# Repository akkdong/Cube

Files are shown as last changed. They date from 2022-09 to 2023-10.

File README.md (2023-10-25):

# M1
ESP32_WT32-SC01, Barometer, GPS, Audio, Battery bank

# M2
ESP32-S3-HMI-V3, Barometer, GPS, Audio, SD, Battery charge

# M3
M5Paper, EPS32-C3, Baromter, GPS, Audio

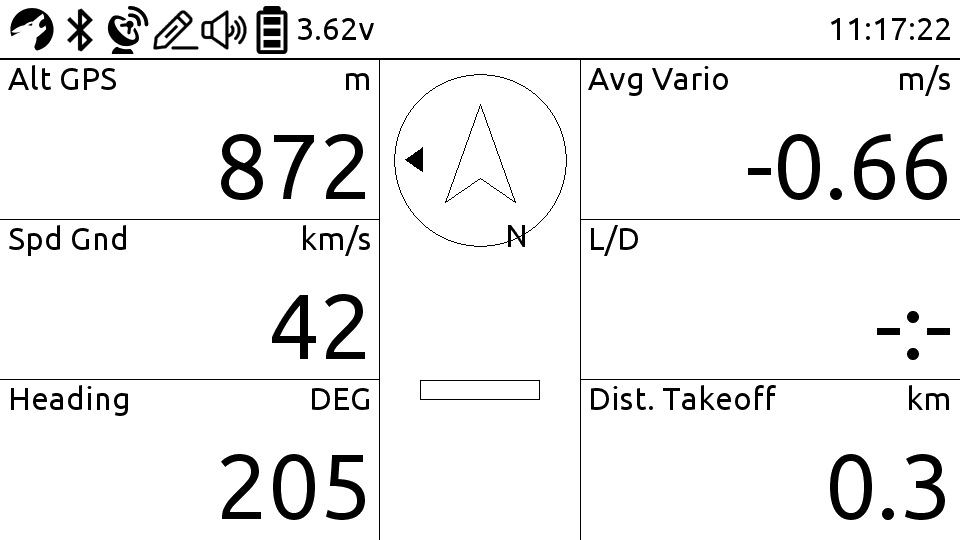
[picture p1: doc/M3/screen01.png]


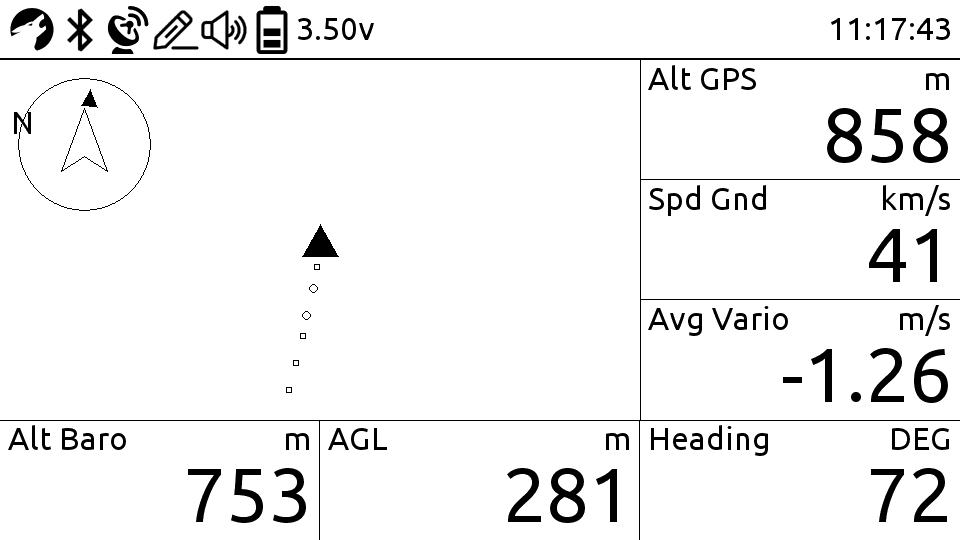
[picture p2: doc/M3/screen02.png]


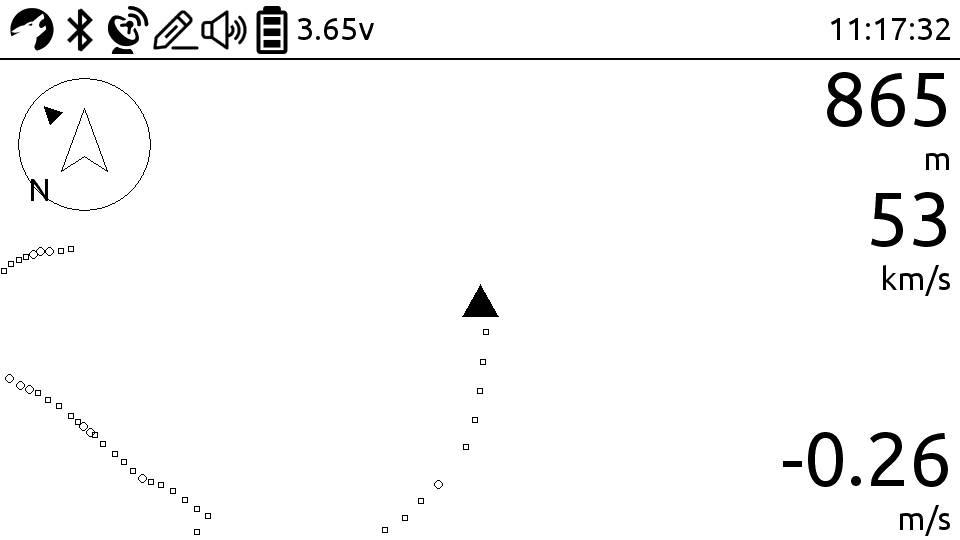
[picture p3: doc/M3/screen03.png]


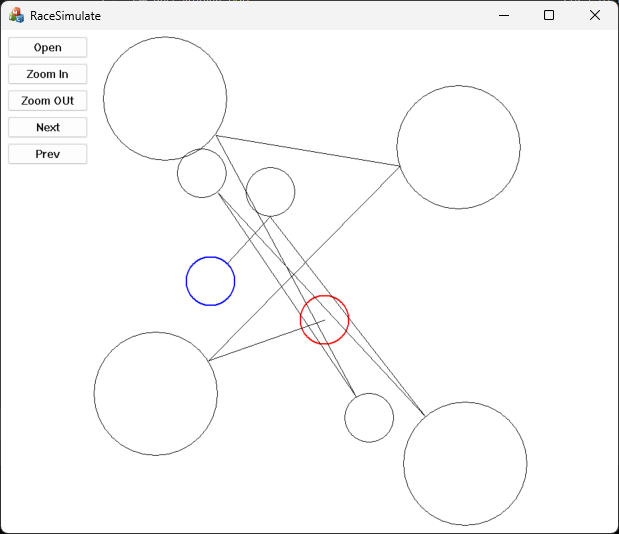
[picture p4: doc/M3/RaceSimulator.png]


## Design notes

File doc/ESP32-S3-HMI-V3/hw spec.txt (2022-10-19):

설명:

ESP32-S3 듀얼 코어 Xtensa 32 비트 LX7 마이크로 프로세서, 384KB ROM, 512KB sram으로 최대 240 MHz. 2.4GHz 와이파이 및 블루투스 5
PSRAM: 2MB 플래시: 8MB
저장: 마이크로 SD 카드 슬롯
디스플레이: 480 × 800 해상도, I2C 정전 식 터치 패널, 4.3 인치 디스플레이
디스플레이 인터페이스: 16 비트, 8080 병렬 통신
오디오: 코덱, 오디오 앰프, 내장 마이크, 스피커
USB: 1x USB-C OTG (DFU/CDC) 포트, 1x USB-C 디버그 포트
센서: 3 축 가속도계, 3 축 자이로 스코프, 온도 및 습도 센서
주변 인터페이스: I2C, SPI, GPIOs
기타: 웨이크 업 및 리셋 버튼, 전원 스위치
전원 공급 장치: 5V / 1A
치수: 110x61x13.5mm

Peripherals

RM68120  		TFT LCD 480x800 4.3inch
FT5X06(0x38)	True Multi-Touch Capacitive TouchPanel Controller
TCA9554(0x3C)	I/O Expander
HTU32D(0x40)	Digital Relative Humidity sensor with Temperature output
ES8311(0x18)	Low Power Mono Audio CODEC
MPU6050(0x68)	6-Axis (Gyro + Accelerometer) MEMS
BMP280(0x76)

TPS63001		High-Efficient Single Inductor Buck-Boost Converter With 1.8-A Switches
NS4150		3W Mono Class D Audio Amplifier

HDC1080(0x40)	High Accuracy Digital Humidity Sensor with Temperature Sensor

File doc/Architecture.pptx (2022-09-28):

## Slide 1

Variometer

MCU (ESP32)

Bluetooth: HID(Keyboard), UART(Variometer)

Mobile

Battery
18650x4

Charger
Booster

S/W

Button(s)
Rotary

Sensor
Pressure
IMU

GPS

Audio
AMP
SPEAKER

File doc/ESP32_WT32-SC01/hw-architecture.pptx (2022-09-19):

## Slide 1

Main Board w/ LCD

Sub Board : GPS, Pressure Sensor, Amplifier, Power-switch, Buttons

Charger Board: Charger & Booster

UART

PWM

I2C

Charger

Pressure Sensor

Amplifier

GPS

Booster

BTN_xxxx

Enter/
Power

Left

Up

Right

PWR_ON

3v3

5v

Down

Prog/
Debug

On/Off

Power Input

Power Switch

Power On Sequence
1. Turn on Charger board
2. Press Enter/Power in Sub Board → Turn on Charge board while holding down Enter/Power
3. Hold down Enter/Power until MCU boot-up
4. Set to high PWR_ON
Power Of Sequence
1. MCU prepare power-off
2. Set to low PWR_ON

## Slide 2

7

1.6

1.6

20

4.2

7.8

7

Top | 2 | 49 | 2 | 27 | 25.4
LCD + Main board | 7 | 47 | 9 | 25 | 23.4
Connector | 7.8 | 40 | 16.8 | 18 | 16.4
Base board (PCB) | 1.6 | 32.2 | 18.4 | 10.2 | 8.6
Supporter | 7 | 30.6 | 25.4 | 8.6 | 7
Battery Charger (PCB) | 1.6 | 23.6 | 27 | 1.6 | -1.6
Battery Holder | 20 | 22 | 47 | -20 | -21.6
Bottom | 2 | 2 | 49 | -22 | -23.6

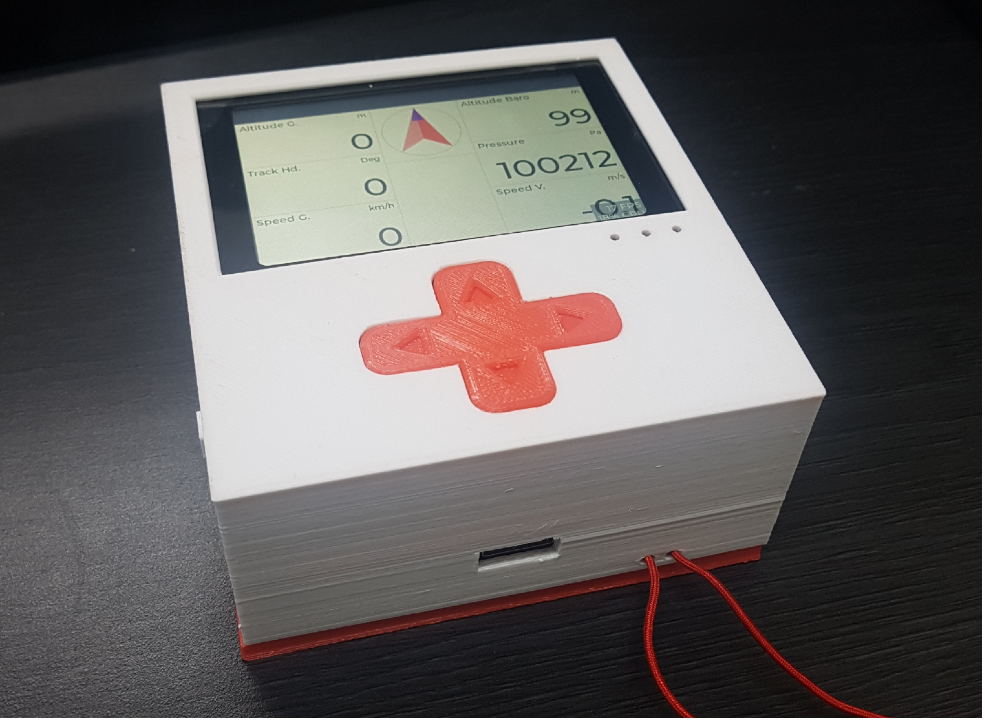
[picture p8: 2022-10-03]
doc/m1-working.png

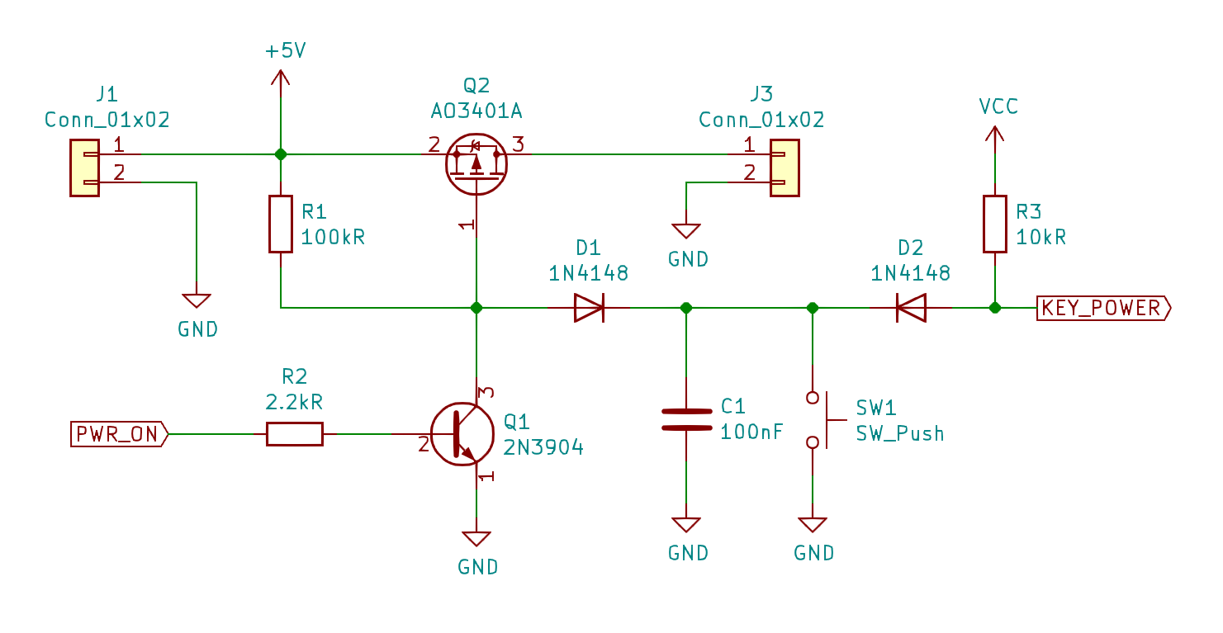
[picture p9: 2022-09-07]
doc/ESP32_WT32-SC01/power-switch.png

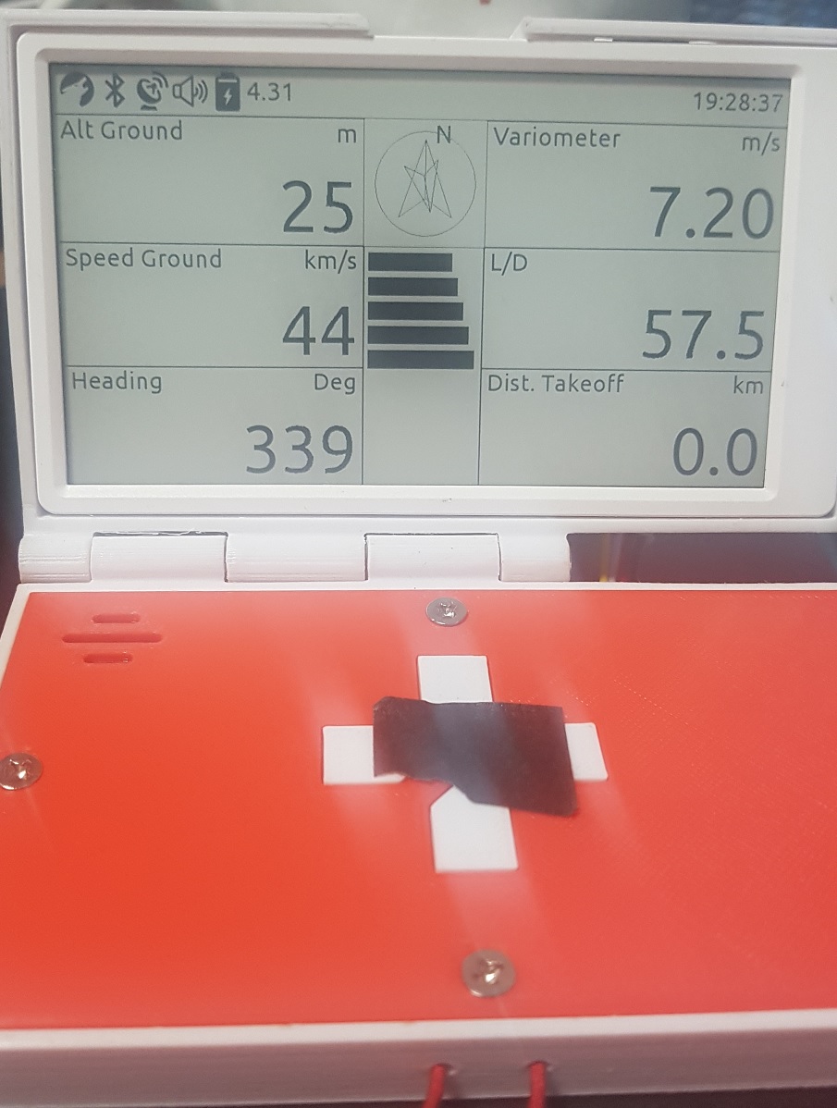
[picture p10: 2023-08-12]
doc/m3-working.jpg

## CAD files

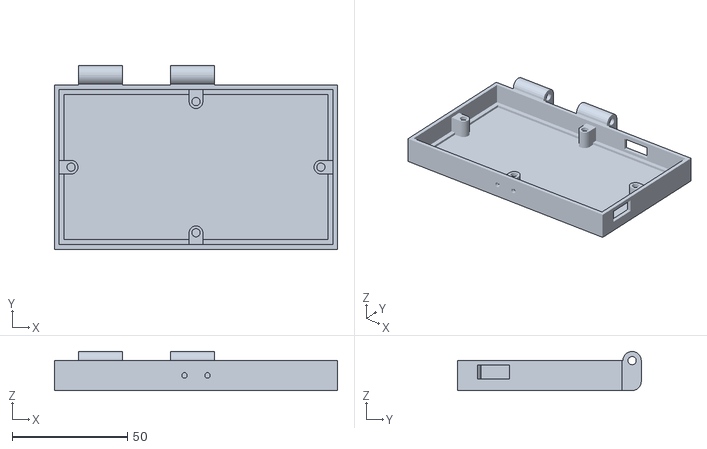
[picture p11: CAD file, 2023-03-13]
case/M3/Main Holder (Meshed).stl
123.0 x 79.8 x 17.0

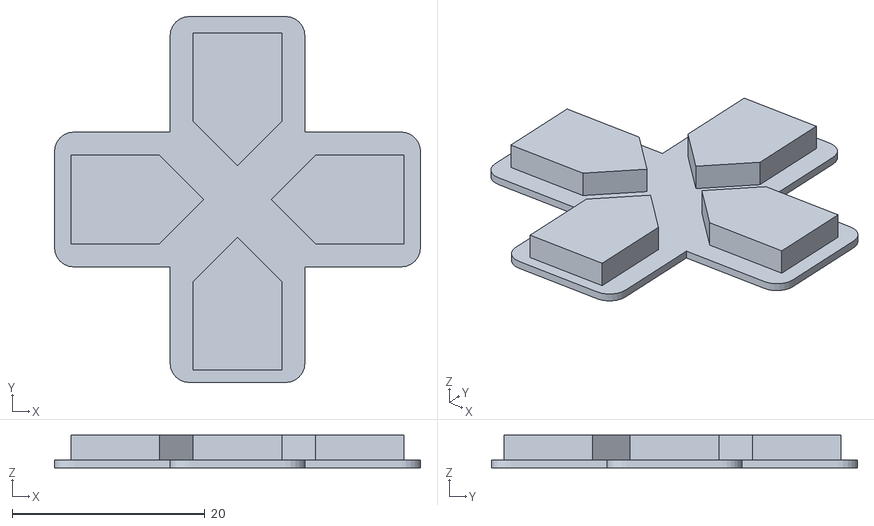
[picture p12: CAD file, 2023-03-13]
case/M3/Main Button (Meshed).stl
38.0 x 38.0 x 3.40

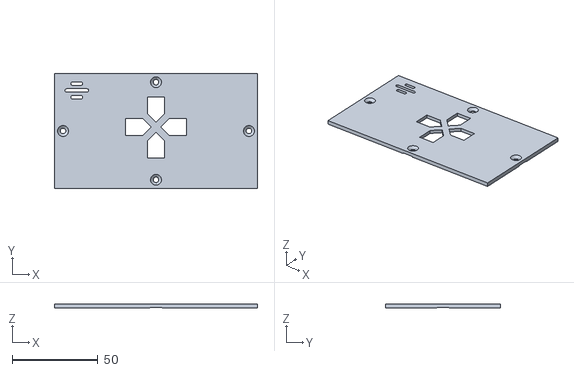
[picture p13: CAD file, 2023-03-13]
case/M3/Main Cover (Meshed).stl
118.6 x 67.0 x 2.40

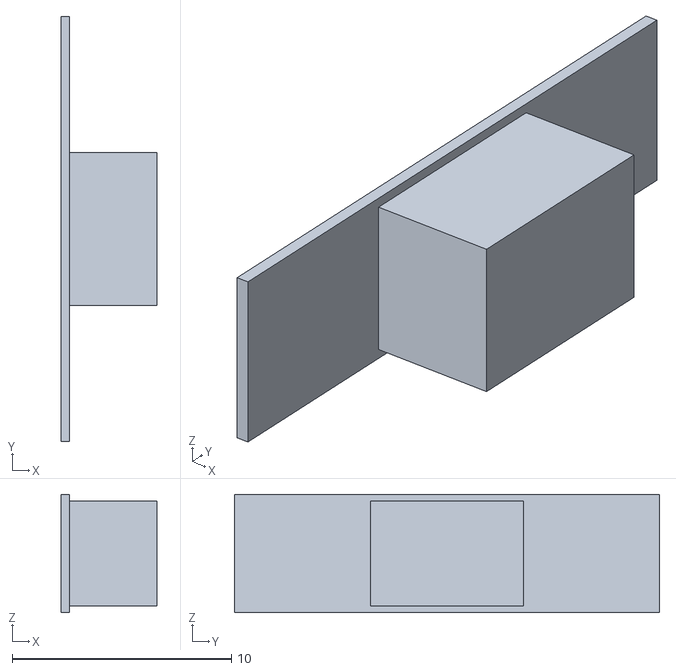
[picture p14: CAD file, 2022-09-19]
case/M1/Button-Power (Meshed).stl
4.40 x 19.4 x 5.40

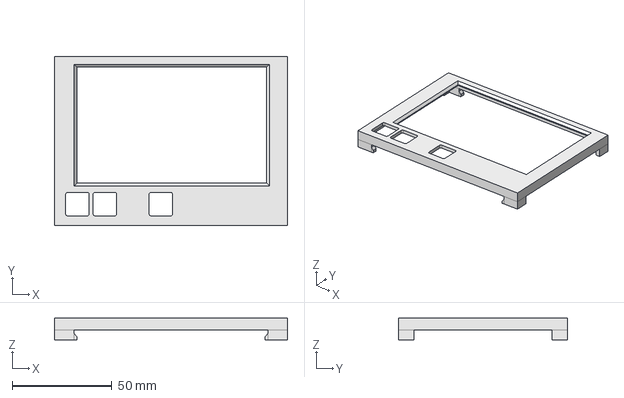
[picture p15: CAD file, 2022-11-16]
case/M2/Case-M2.FCStd
117.0 x 85.0 x 10.8 mm

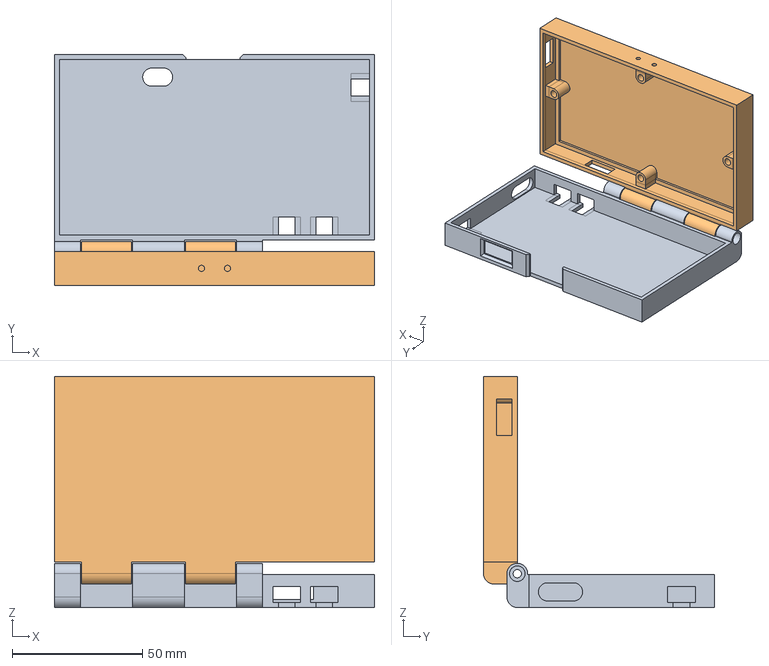
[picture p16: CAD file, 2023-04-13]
case/M3/M3.FCStd
123.0 x 88.8 x 88.8 mm
Disp Holder
Main Holder

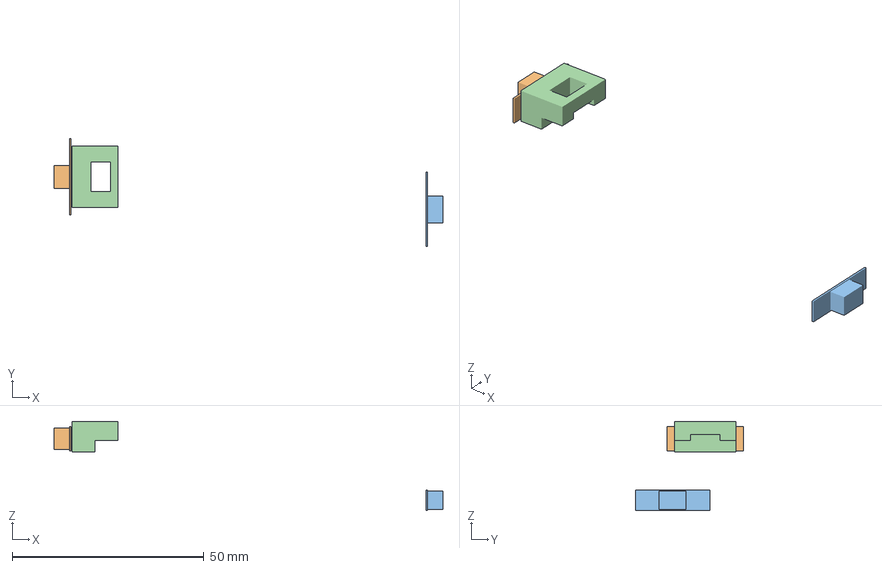
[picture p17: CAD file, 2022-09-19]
case/M1/Cube-Vario.FCStd
101.4 x 28.2 x 23.3 mm
Button-Guide
Button-Enter
Button-Power
Button-Guide (Meshed)
Button-Enter (Meshed)
Button-Power (Meshed)

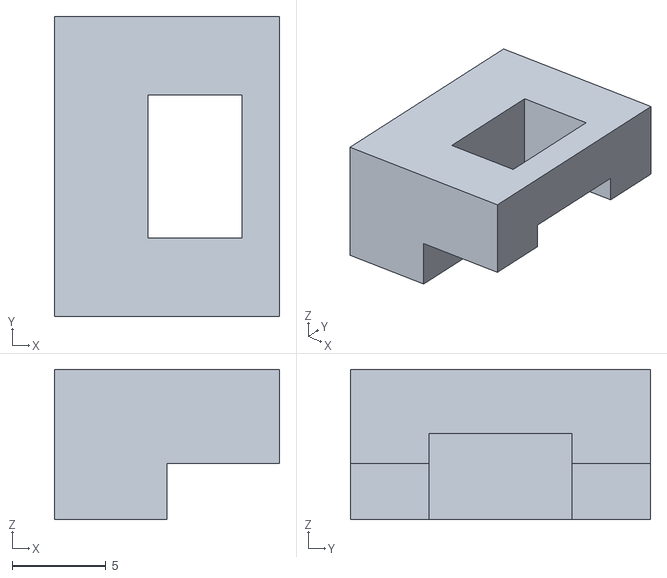
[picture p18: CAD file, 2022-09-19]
case/M1/Button-Guide (Meshed).stl
12.0 x 16.0 x 8.00

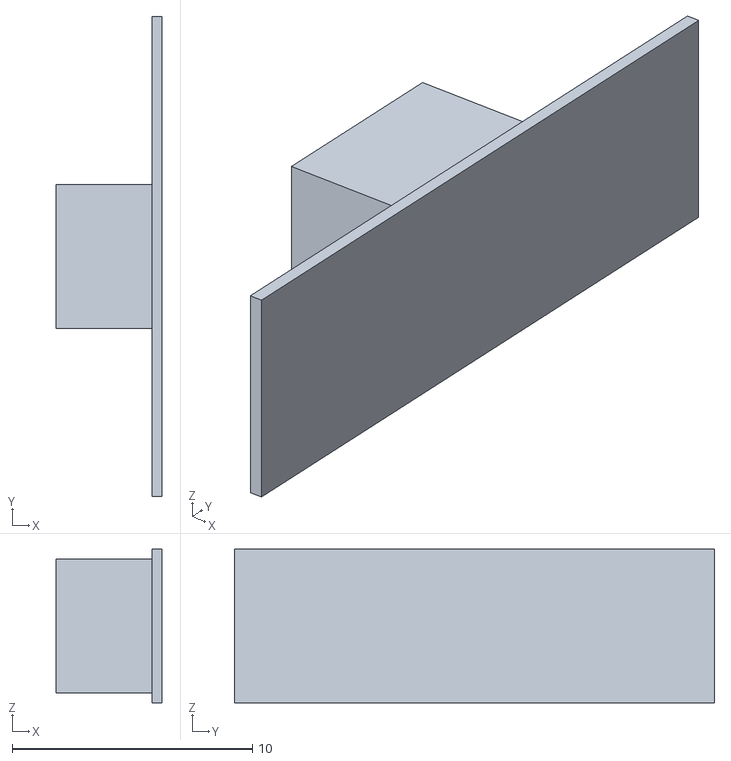
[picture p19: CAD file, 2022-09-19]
case/M1/Button-Enter (Meshed).stl
4.40 x 20.0 x 6.40

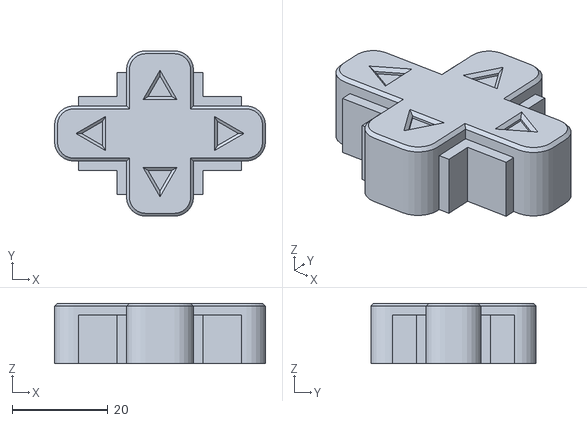
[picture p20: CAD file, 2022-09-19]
case/M1/Button-Cross (Meshed).stl
44.0 x 34.5 x 12.6

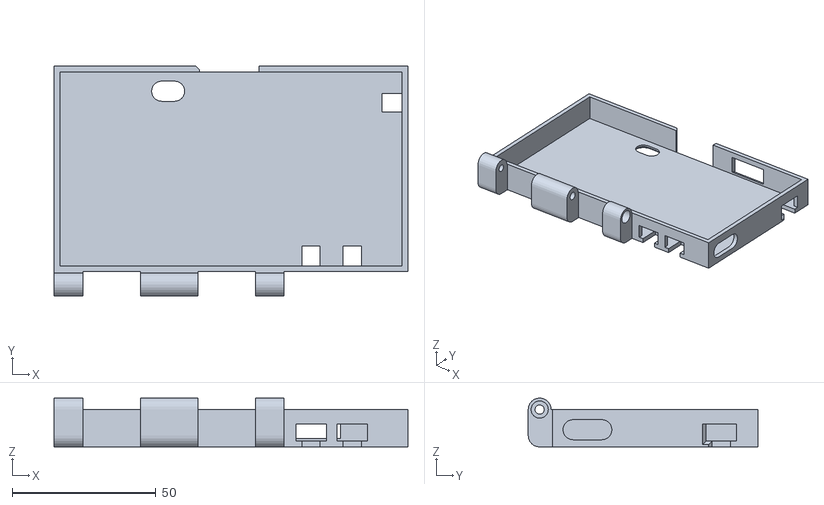
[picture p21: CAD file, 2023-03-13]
case/M3/Disp Holder (Meshed).stl
123.0 x 79.8 x 17.0

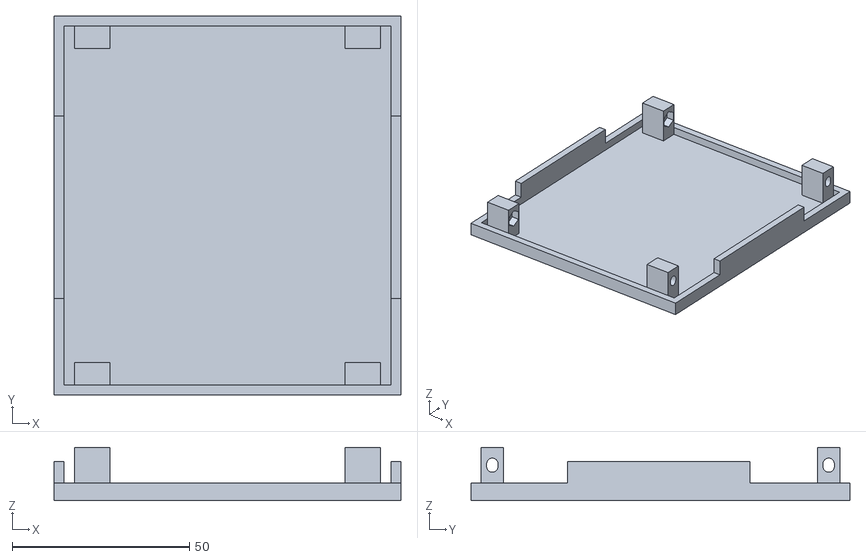
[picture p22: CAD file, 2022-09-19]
case/M1/Base (Meshed).stl
98.0 x 107.0 x 15.0

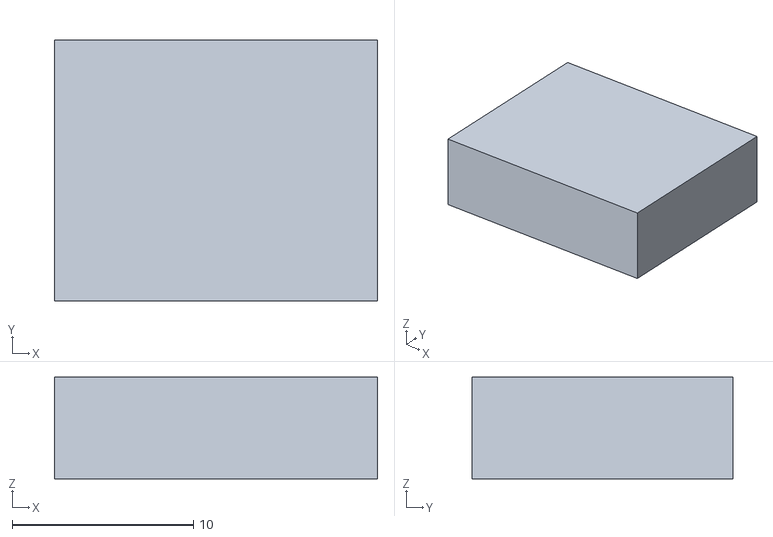
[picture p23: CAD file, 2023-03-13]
case/M3/PSensor Cover (Meshed).stl
17.8 x 14.4 x 5.60

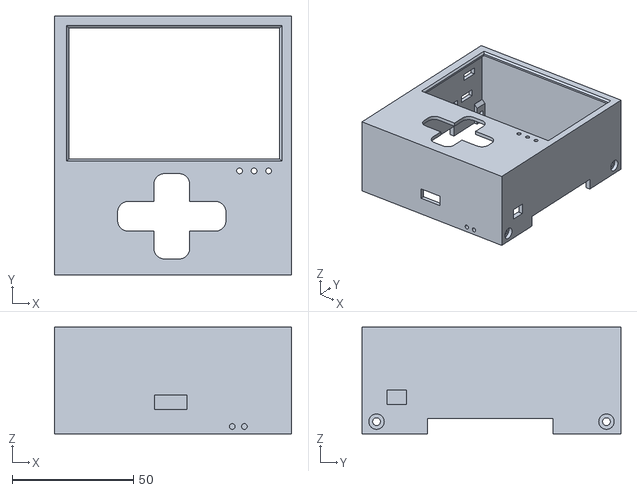
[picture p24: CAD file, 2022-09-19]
case/M1/Cover (Meshed).stl
98.0 x 107.0 x 44.0

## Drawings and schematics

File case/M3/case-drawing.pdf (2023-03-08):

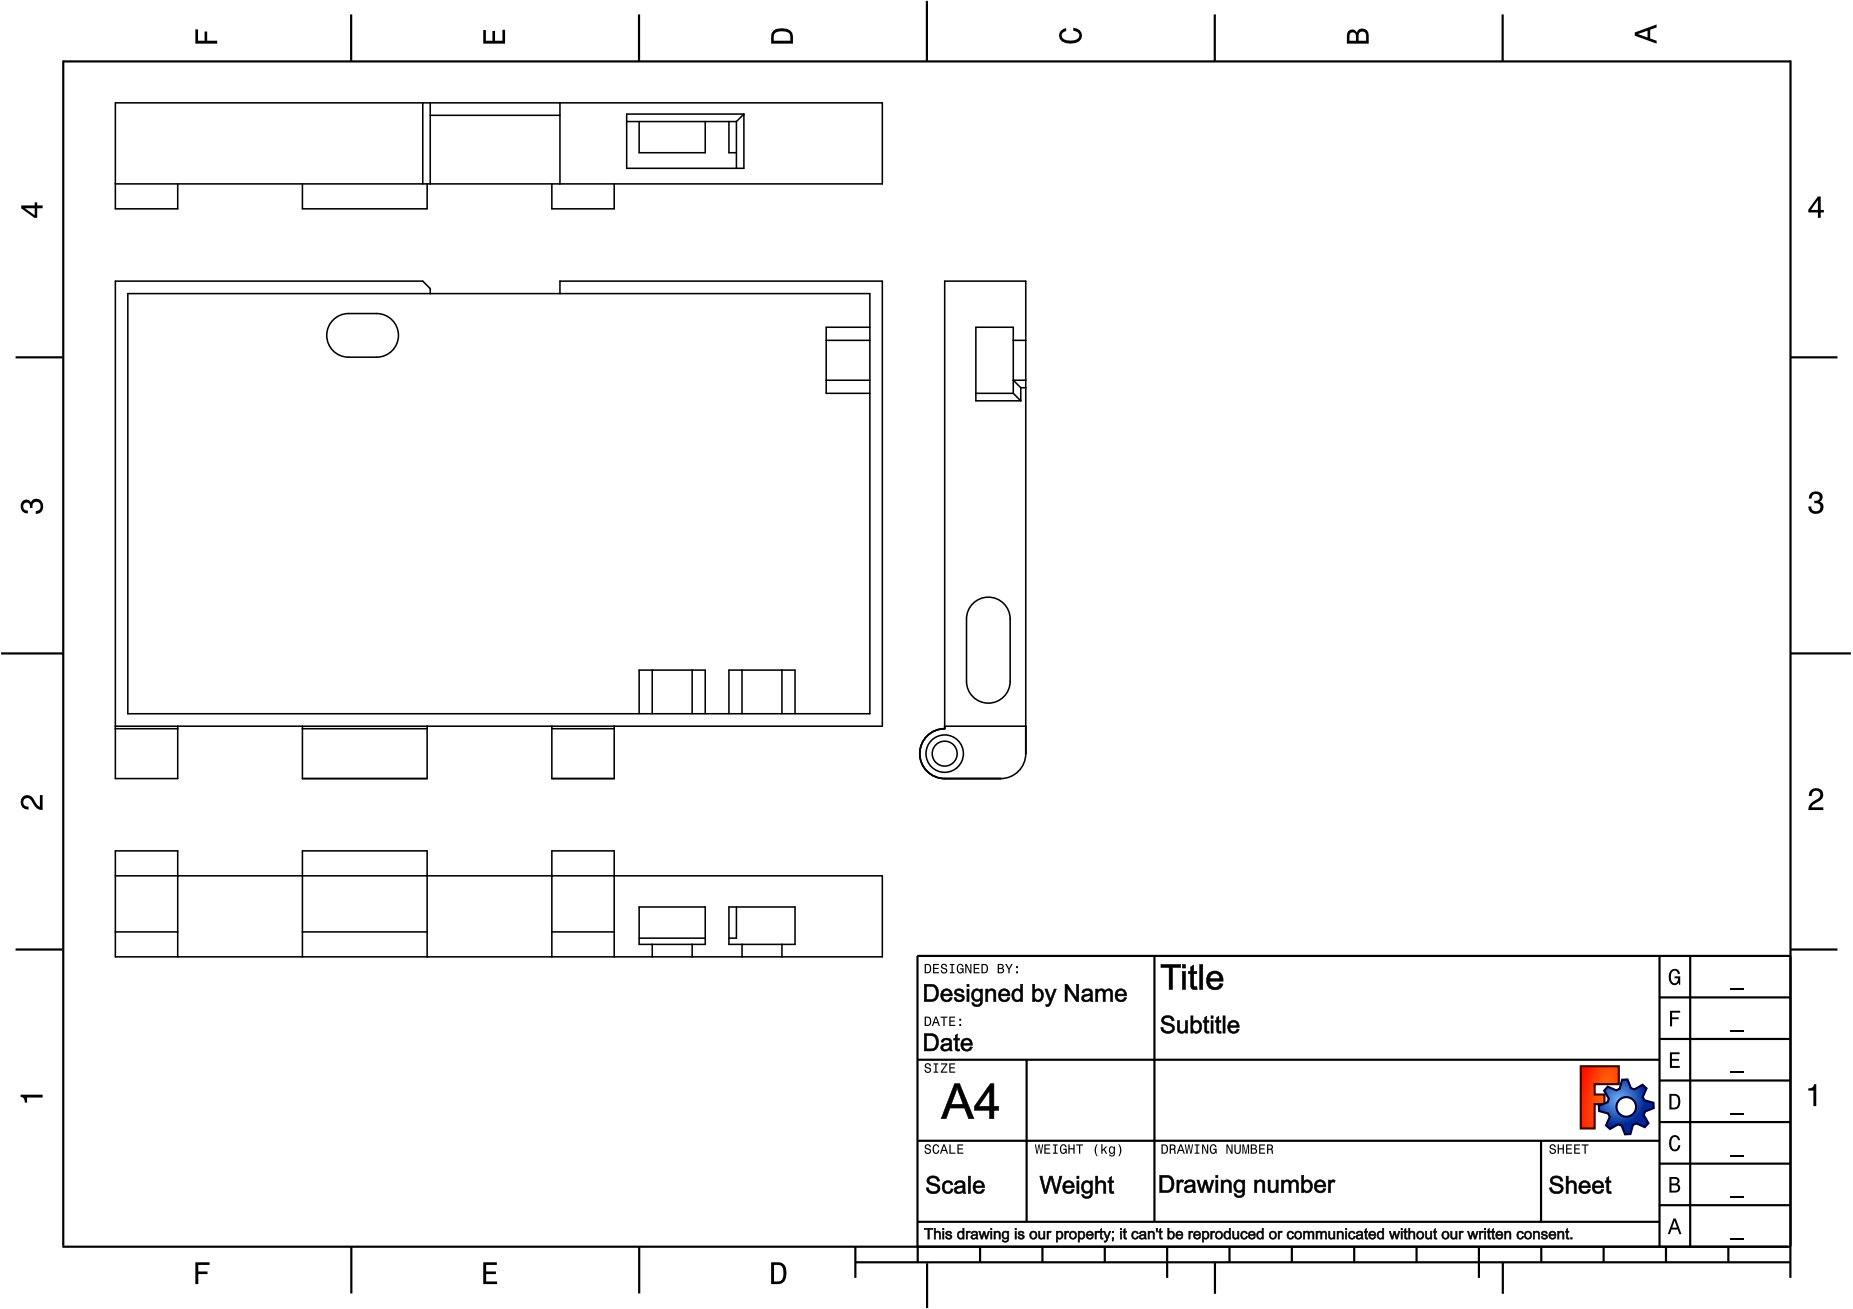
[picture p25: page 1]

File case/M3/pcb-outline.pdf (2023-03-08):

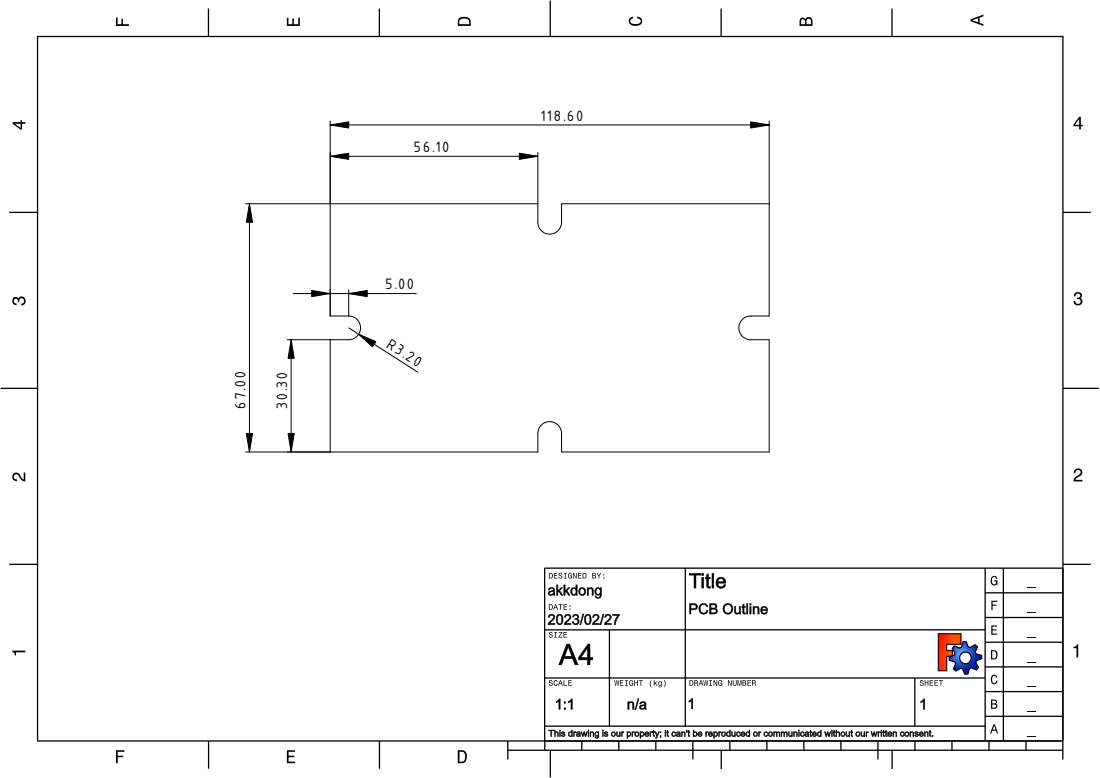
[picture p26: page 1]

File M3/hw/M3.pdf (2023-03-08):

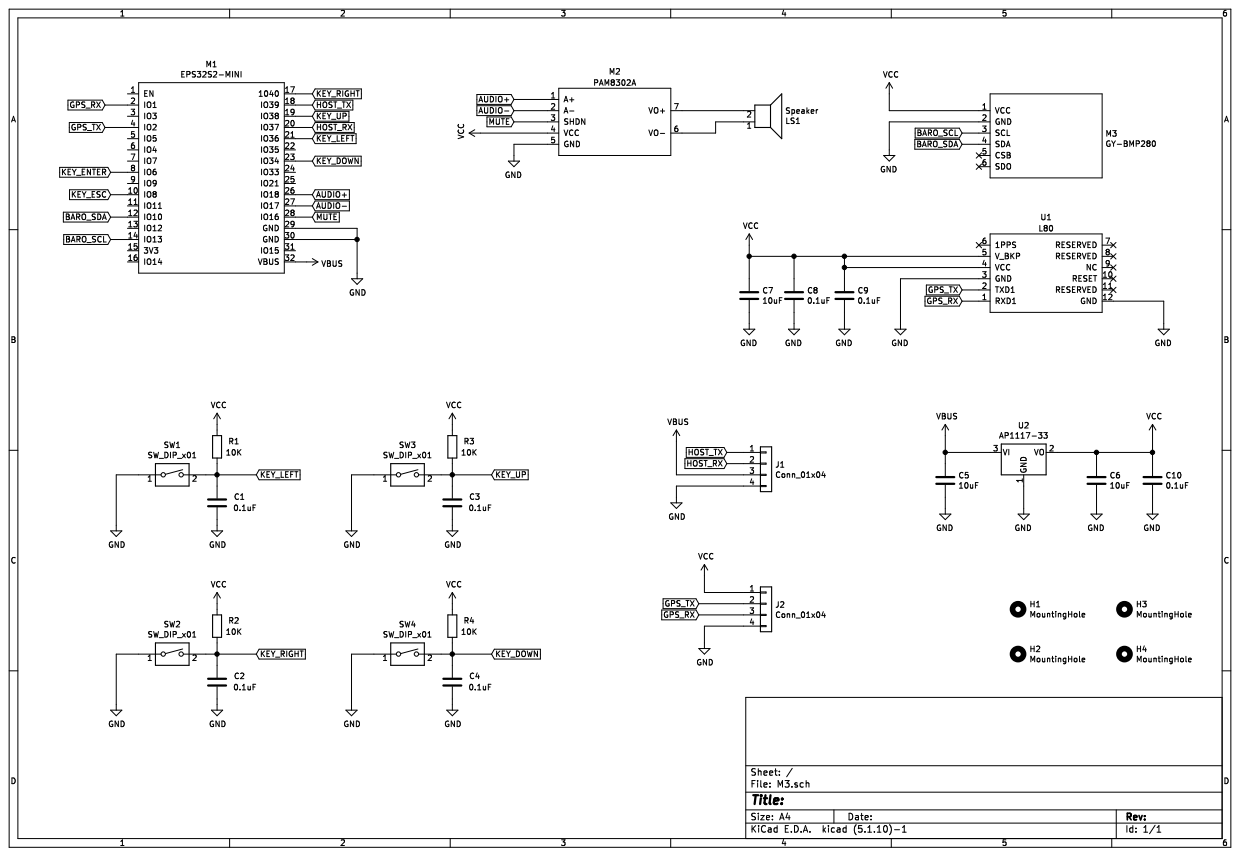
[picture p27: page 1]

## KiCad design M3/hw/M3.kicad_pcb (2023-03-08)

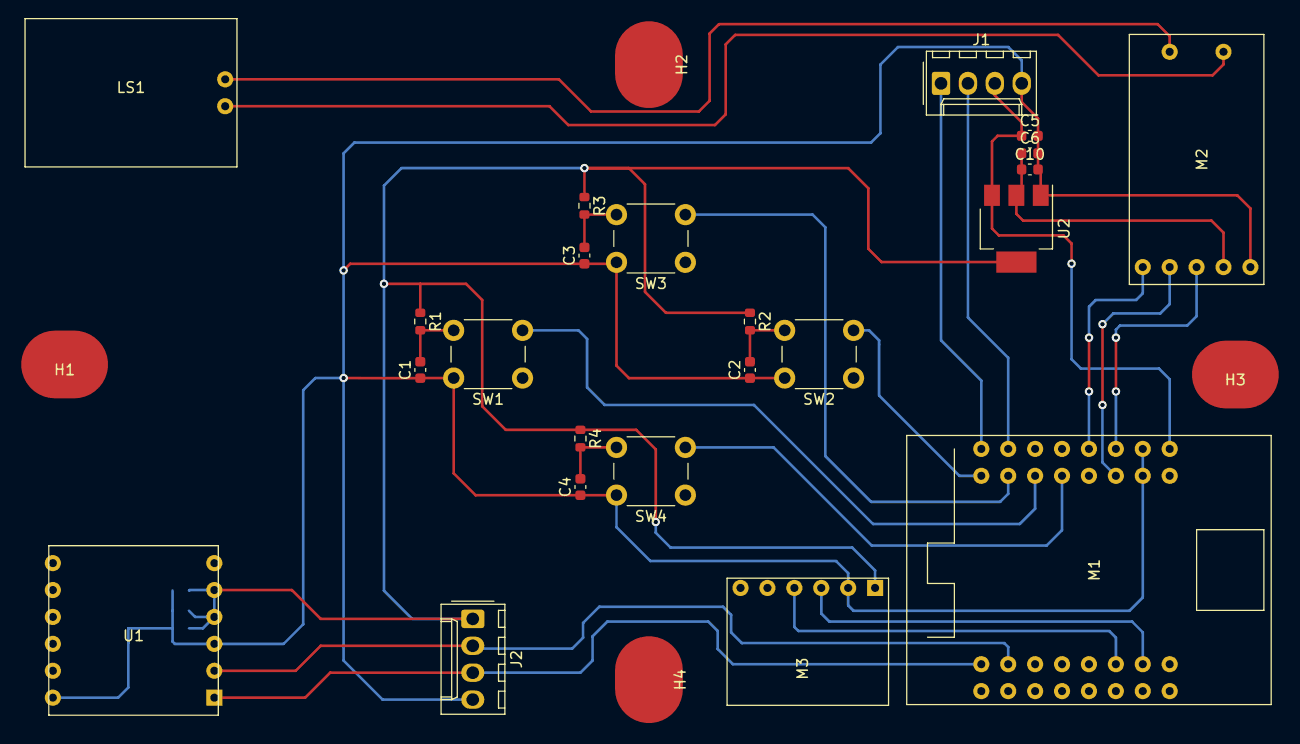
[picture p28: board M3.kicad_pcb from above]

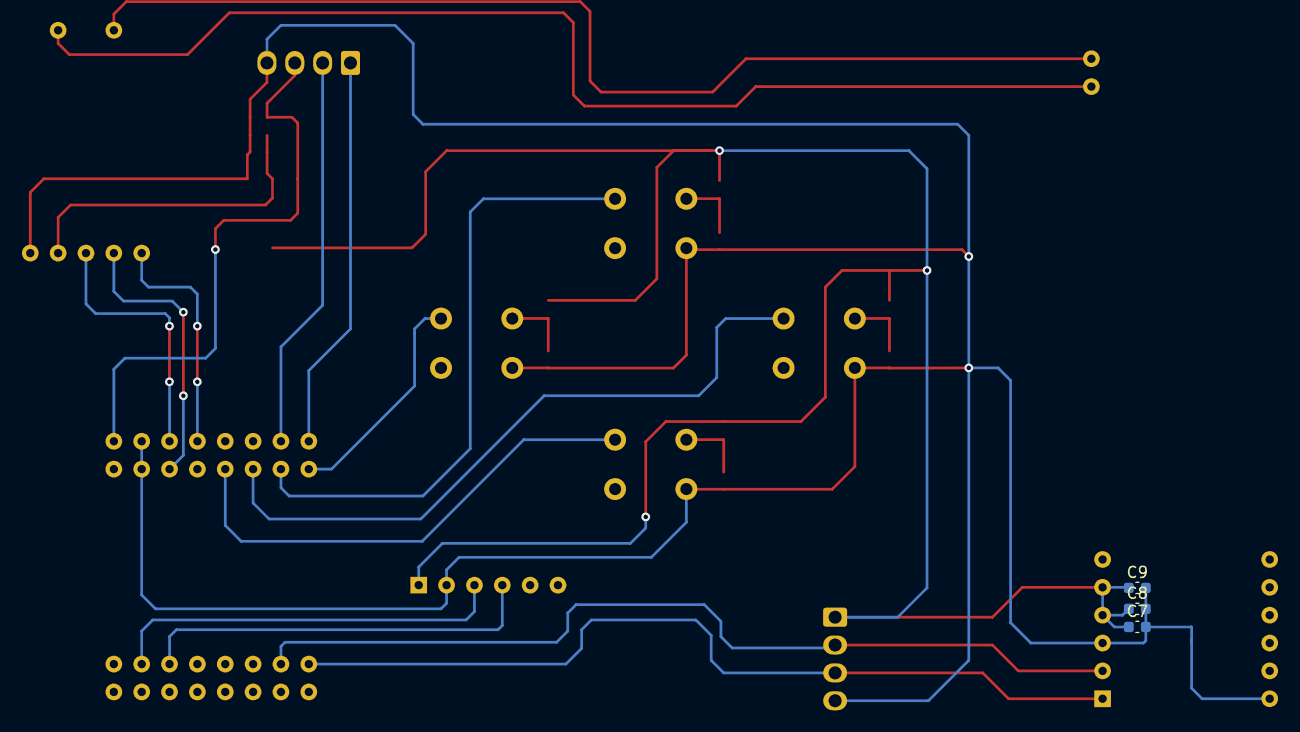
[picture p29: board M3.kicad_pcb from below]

Board: 2 copper layers, 30 parts (3 on the bottom side), 18 nets.

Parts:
C1, C2, C3, C4, C8, C9, C10: 0.1uF; C_0603_1608Metric
C5, C6, C7: 10uF; C_0603_1608Metric
H1, H2, H3, H4: MountingHole; M3_HOLE
J1, J2: Conn_01x04; Molex_KK-254_AE-6410-04A_1x04_P2.54mm_Vertical
LS1: Speaker; ROUND-SPEKAER
M1: EPS32S2-MINI; ESP32S2-MINI
M2: PAM8302A
M3: GY-BMP280
R1, R2, R3, R4: 10K; R_0603_1608Metric
SW1, SW2, SW3, SW4: SW_DIP_x01; SW_PUSH_6mm
U1: L80
U2: AP1117-33; SOT-223-3_TabPin2

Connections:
AUDIO+: M1.26, M2.1
AUDIO-: M1.27, M2.2
BARO_SCL: M1.14, M3.3
BARO_SDA: M1.12, M3.4
GND: C1.1, C2.1, C3.1, C4.1, C5.2, C6.2, C7.2, C8.2, C9.2, C10.2, J1.4, J2.4, M1.29, M1.30, M2.5, M3.2, SW1.1, SW2.1, SW3.1, SW4.1, U1.3, U1.12, U2.1
GPS_RX: J2.3, M1.2, U1.1
GPS_TX: J2.2, M1.4, U1.2
HOST_RX: J1.2, M1.20
HOST_TX: J1.1, M1.18
KEY_DOWN: C4.2, M1.23, R4.2, SW4.2
KEY_LEFT: C1.2, M1.21, R1.2, SW1.2
KEY_RIGHT: C2.2, M1.17, R2.2, SW2.2
KEY_UP: C3.2, M1.19, R3.2, SW3.2
MUTE: M1.28, M2.3
unnamed: LS1.1, M2.6
unnamed: LS1.2, M2.7
VBUS: C5.1, J1.3, M1.32, U2.3
VCC: C6.1, C7.1, C8.1, C9.1, C10.1, J2.1, M2.4, M3.1, R1.1, R2.1, R3.1, R4.1, U1.4, U1.5, U2.2

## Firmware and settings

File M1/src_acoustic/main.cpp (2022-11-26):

// main.cpp
//

#include <Arduino.h>
#include "device_defines.h"
#include "logger.h"
#include "app.h"
#include "utils.h"
#include "BLEVario.h"
#include "Variometer.h"
#include "VarioSentence.h"
#include "LocationParser.h"
#include "Beeper.h"
#include "Bme280.h"
#include "FT6206.h"
#include "SineGenerator.h"
#include "Keypad.h"

#define VFILTER_HARINAIR_KF2     1
#define VFILTER_HARINAIR_KF4d    2
#define VFILTER_ROBIN_KF         3

#define USE_KALMAN_FILTER        VFILTER_HARINAIR_KF2

#if USE_KALMAN_FILTER == VFILTER_HARINAIR_KF2
#include "VarioFilter_HarInAirKF2.h"
#elif USE_KALMAN_FILTER == VFILTER_HARINAIR_KF4d
#include "VarioFilter_HarInAirKF4d.h"
#elif USE_KALMAN_FILTER == VFILTER_ROBIN_KF
#include "VarioFilter_RobinKF.h"
#else
#error "Invalid vario kalman-filter"
#endif


//
// button
//


//
// baro-settings
//

static Bme280Settings varioSettings() 
{
	return {
		.mode = Bme280Mode::Normal,
		.temperatureOversampling = Bme280Oversampling::X2,
		.pressureOversampling = Bme280Oversampling::X16,
		.humidityOversampling = Bme280Oversampling::Off,
		.filter = Bme280Filter::Off,
		.standbyTime = Bme280StandbyTime::Ms0_5			
	};
}

//
Bme280TwoWire	baro;
SineGenerator	beep;
FT6206			touch;

Variometer      vario;
LocationParser  locParser;
VarioSentence   varioNmea(VARIOMETER_DEFAULT_NMEA_SENTENCE);
Beeper          beeper;

#if USE_KALMAN_FILTER == VFILTER_HARINAIR_KF2
VarioFilter_HarInAirKF2     varioFilter;
#elif USE_KALMAN_FILTER == VFILTER_HARINAIR_KF4d
VarioFilter_HarInAirKF4d    varioFilter;
#elif USE_KALMAN_FILTER == VFILTER_ROBIN_KF
VarioFilter_RobinKF         varioFilter;
#endif 

BLEVario        bleDevice;


class VarioKeypad : public KeypadCallback
{
public:
    VarioKeypad() {}

    virtual void OnPressed(uint8_t key) {
        Serial.printf("Key pressed: %02X\n", key);
        if (key != KEY_ENTER)
            bleDevice.press(key);
    }

    virtual void OnLongPressed(uint8_t key) {
        Serial.printf("Key long-pressed: %02X\n", key);
        if (key == KEY_ENTER)
        {
            Serial.println("Turn-off Variometer!!");

            digitalWrite(POWER_ON, LOW);
        }
    }

    virtual void OnReleased(uint8_t key) {
        Serial.printf("Key released: %02X\n", key);
        if (key != KEY_ENTER)
            bleDevice.release(key);
    }
};

VarioKeypad     keyCallback;
Keypad          keyPad(&keyCallback);



app_conf_t*     app_conf = NULL;


static Tone melodyStart[] =
{
    { NOTE_C5, 400, 500 },
    { NOTE_E5, 400, 500 },
    { NOTE_G5, 400, 500 },
};

//
//
//

extern "C" app_conf_t* app_get_conf()
{
    static app_conf_t conf;

    return &conf;
}

extern "C" void app_config_init(app_conf_t* conf)
{
	//
    memset(conf, 0, sizeof(app_conf_t));

    //
    conf->bearing = -1;
}



//
//
//

void setup() {
	// initialize pin-mode
	pinMode(POWER_ON, OUTPUT);
	pinMode(BTN_SEL, INPUT);
	pinMode(BTN_LEFT, INPUT);
	pinMode(BTN_RIGHT, INPUT);
	pinMode(BTN_UP, INPUT);	
	pinMode(BTN_DOWN, INPUT);

    digitalWrite(POWER_ON, HIGH);

    //
    app_conf = app_get_conf();
    app_config_init(app_conf);    

    //
    Serial.begin(115200);
    Serial2.begin(9600, SERIAL_8N1, UART1_RX, UART1_TX);
    bleDevice.begin();

	// setup-wire
	Wire.begin(I2C0_SDA, I2C0_SCL);

	// setup-pwm
	beep.begin(SineGenerator::USE_CHANNEL_1);
	
	// setup-barometer
	baro.begin(Bme280TwoWireAddress::Primary);
	baro.setSettings(varioSettings());		
	
	// setup-touch
	touch.begin();
    // 
    keyPad.begin(CreateKeypadInput());

    //
    // start-vario
    //   make-top-menu
    //   load-scren -> show active-screen
    //   initialize: batery, vario
    //      --> update vario/device state
    //
    // 

    #if USE_KALMAN_FILTER == VFILTER_HARINAIR_KF2
    varioFilter.begin(400.0f, 1000.0f, 1.0f, 0);
    #elif USE_KALMAN_FILTER == VFILTER_HARINAIR_KF4d

    // injects additional uncertainty depending on magnitude of acceleration
    // helps respond quickly to large accelerations while heavily filtering
    // in low acceleration situations.  Range : 0.5 - 1.5
    #define KF_ACCEL_VARIANCE_DEFAULT   100     // 50 ~ 150
    #define KF_ADAPT_DEFAULT            100     // 50 ~ 150

    varioFilter.begin(1000.0f * KF_ACCEL_VARIANCE_DEFAULT, KF_ADAPT_DEFAULT / 100.0f, 0, 0, 0);
    #elif USE_KALMAN_FILTER == VFILTER_ROBIN_KF
    varioFilter.Configure(30.0f, 4.0f, altitude);
    #endif    

    vario.begin(CreateBarometer(), &varioFilter);
    locParser.begin(CreateLocationDataSource());
    beeper.begin(CreateTonePlayer());

    beeper.playMelody(melodyStart, sizeof(melodyStart) / sizeof(melodyStart[0]));
}

void loop() {
    // forward serial to bluetooth and reverse : debug purpose only
    #if 1
    while (Serial.available())
    {
        int ch = Serial.read();
        bleDevice.write(ch);
    }

    while (bleDevice.available())
    {
        int ch = bleDevice.read();
        Serial.write(ch);
    }
    #endif

    // button processing
    keyPad.update();
    /*
    for (size_t i = 0; i < sizeof(_m1) / sizeof(_m1[0]); i++)
    {
        key_map* kmap = &_m1[i];
        int value = digitalRead(kmap->pin);
        uint8_t state = 0; // release
        if ((kmap->active == 0 && value == 0) || (kmap->active != 0 && value != 0))
            state = 1; // press

        if (kmap->state != state)
        {
            if (state)
            {
                bleDevice.press(kmap->key);
                Serial.printf("Press: %02X\n", kmap->key);
            }
            else
            {
                bleDevice.release(kmap->key);
                Serial.printf("Release: %02X\n", kmap->key);
            }

            kmap->state = state;
        }
    }
    */

    #if 1
    // update each state
    locParser.update();
    int varioUpdated = vario.update();
    beeper.update();

    // location is fixed
    if (locParser.availableLocation()) 
    {
        LOGi("[GPS] %f,%f %f", locParser.getLongitude(), locParser.getLatitude(), locParser.getAltitude());
        app_conf->latitude = locParser.getLatitude();
        app_conf->longitude = locParser.getLongitude();
        app_conf->altitudeGPS = locParser.getAltitude();
        app_conf->speedGround = locParser.getSpeed();
        app_conf->heading = locParser.getHeading();
        app_conf->dirty = 1;

        locParser.resetLocation();        
    }

    // vario-state updated
    if (varioUpdated > 0) 
    {
        //static uint32_t lastTick = millis();
        //static uint32_t tick[30];
        static uint32_t count = 0;
        static float vSpeed = 0;

        app_conf->altitudeBaro = vario.getAltitudeFiltered();
        app_conf->pressure = vario.getPressure();
        app_conf->temperature = vario.getTemperature();
        app_conf->speedVertActive = vario.getVelocity();

        vSpeed += app_conf->speedVertActive;

        if (!bleDevice.isConnected())
            beeper.setVelocity(app_conf->speedVertActive);

        //tick[count] = millis();
        count += 1;
        if ((count % 5) == 0)
        {
            /*
            LOGi("Update vario-relative stubs: %u", millis() - lastTick);
            LOGi("  %u %u %u %u %u %u %u %u %u %u %u %u %u %u %u %u %u %u %u %u",
                tick[1] - tick[0],
                tick[2] - tick[1],
                tick[3] - tick[2],
                tick[4] - tick[3],
                tick[5] - tick[4],
                tick[6] - tick[5],
                tick[7] - tick[6],
                tick[8] - tick[7],
                tick[9] - tick[8],
                tick[10] - tick[9],
                tick[11] - tick[10],
                tick[12] - tick[11],
                tick[13] - tick[12],
                tick[14] - tick[13],
                tick[15] - tick[14],
                tick[16] - tick[15],
                tick[17] - tick[16],
                tick[18] - tick[17],
                tick[19] - tick[18],
                tick[20] - tick[19]);
            */

            app_conf->speedVertLazy = vSpeed / count;
            app_conf->dirty = 1;

            vSpeed = 0;
            count = 0;
            //lastTick = millis();
        }

        //
        if (varioNmea.checkInterval())
            varioNmea.begin(app_conf->altitudeAGL, app_conf->speedVertLazy, app_conf->temperature, 0.0f);
    }

    // vario-sentense available?
    static int bt_lock_state = 0; // 0: unlocked, 1: locked_by_vario, 2: locked_by_gps
    if ((bt_lock_state == 0 && varioNmea.available()) || (bt_lock_state == 1))
    {
        bt_lock_state = 1;

        while (varioNmea.available())
        {
            int ch = varioNmea.read();
            if (ch < 0)
                break;

            bleDevice.writeBuffered(ch);
            //Serial.write(ch);

            if (ch == '\n')
            {
                bt_lock_state = 0;
                break;
            }
        }

        if (bt_lock_state == 0 /*|| bleDevice.uartBufferIsFull()*/)
            bleDevice.flush();
    }

    // nmea-sentense avaialble?
    if ((bt_lock_state == 0 && locParser.availableNmea()) || (bt_lock_state == 2))
    {
        bt_lock_state = 2;

        while (locParser.availableNmea())
        {
            int ch = locParser.readNmea();
            if (ch < 0)
                break;

            bleDevice.writeBuffered(ch);
            //Serial.write(ch);

            if (ch == '\n')
            {
                bt_lock_state = 0;
                break;
            }
        }

        if (bt_lock_state == 0 /*|| bleDevice.uartBufferIsFull()*/)
            bleDevice.flush();
    }    
    #endif
}

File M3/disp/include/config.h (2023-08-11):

// config.h
//

#ifndef __CONFIG_H__
#define __CONFIG_H__

#ifndef PI
#define PI 3.1415926535897932384626433832795
#define HALF_PI 1.5707963267948966192313216916398
#define TWO_PI 6.283185307179586476925286766559
#define DEG_TO_RAD 0.017453292519943295769236907684886
#define RAD_TO_DEG 57.295779513082320876798154814105
#endif


// Variometer default settings
//

#define VARIOMETER_TIME_ZONE					(9.0f)	// GMT+9
#define VARIOMETER_BEEP_VOLUME					(100)	// percentage (0 ~ 100)
#define VARIOMETER_EFFECT_VOLUME				(100)

#define VARIOMETER_SINKING_THRESHOLD 			(-3.0)
#define VARIOMETER_CLIMBING_THRESHOLD 			(0.2)
#define VARIOMETER_SENSITIVITY 					(0.12)
#define VARIOMETER_MIN_VELOCITY					(-10)
#define VARIOMETER_MAX_VELOCITY					(10)

#define VARIOMETER_LXNAV_SENTENCE				(1)
#define VARIOMETER_LK8_SENTENCE					(2)
#define VARIOMETER_DEFAULT_NMEA_SENTENCE		VARIOMETER_LK8_SENTENCE

#define VARIOMETER_SENTENCE_DELAY				(1000)  //  tick = 1000/25 = 40, 25 tick = 1000
#define VARIOMETER_DEFAULT_DAMPING_FACTOR 		(0.05)	// x1 = x0 + (x1 - x0) * damping_factor

#define SENSOR_UPDATE_FREQUENCY                 (25)    // 25Hz


// Kalman filter settings
//

// Variometer class configuration
#define POSITION_MEASURE_STANDARD_DEVIATION 	(0.1)
#define ACCELERATION_MEASURE_STANDARD_DEVIATION (0.3)

// KalmanFilter class configuration
#define KF_ZMEAS_VARIANCE       				(500.0f)
#define KF_ZACCEL_VARIANCE      				(8000.0f)
#define KF_ACCELBIAS_VARIANCE   				(1.0f)


// Flight detection settings
//

#define FLIGHT_START_MIN_SPEED 					(6.0)		// 6Km/h
#define FLIGHT_STOP_MIN_SPEED					(2.0)
#define FLIGHT_LANDING_THRESHOLD 				(30000)		// 30s
#define FLIGHT_LOGGING_INTERVAL					(1000)		// 1s


// Auto shutdown threshold
//

#define STABLE_SINKING_THRESHOLD				(-0.2)
#define STABLE_CLIMBING_THRESHOLD				(0.2)
#define AUTO_SHUTDOWN_THRESHOLD					(10*60*1000)	// 10min (600s)

// Low battery threshold
//

#define LOW_BATTERY_THRESHOLD					(3.2)	// VBAT drop down about 0.4v. so rear threshold voltage is -0.4
#define SHUTDOWN_HOLD_TIME						(2000)


#endif // __CONFIG_H__

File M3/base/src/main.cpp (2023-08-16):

#include <Arduino.h>
#include "bsp.h"
#include "logger.h"

#include "Variometer.h"
#include "VarioSentence.h"
#include "keypad.h"
#include "Beeper.h"
#include "CubeSentence.h"
#include "HostCommand.h"

#ifndef DEBUG_MODE
#define DEBUG_MODE               0
#endif // DEBUG_MODE

#define VFILTER_HARINAIR_KF2     1
#define VFILTER_HARINAIR_KF3     2
#define VFILTER_HARINAIR_KF4d    3
#define VFILTER_ROBIN_KF         4

#define USE_KALMAN_FILTER        VFILTER_HARINAIR_KF3

#if USE_KALMAN_FILTER == VFILTER_HARINAIR_KF2
#include "VarioFilter_HarInAirKF2.h"
#elif USE_KALMAN_FILTER == VFILTER_HARINAIR_KF3
#include "VarioFilter_HarInAirKF3.h"
#elif USE_KALMAN_FILTER == VFILTER_HARINAIR_KF4d
#include "VarioFilter_HarInAirKF4d.h"
#elif USE_KALMAN_FILTER == VFILTER_ROBIN_KF
#include "VarioFilter_RobinKF.h"
#else
#error "Invalid vario kalman-filter"
#endif

#if USE_KALMAN_FILTER == VFILTER_HARINAIR_KF2
VarioFilter_HarInAirKF2     varioFilter;
#elif USE_KALMAN_FILTER == VFILTER_HARINAIR_KF3
VarioFilter_HarInAirKF3     varioFilter;
#elif USE_KALMAN_FILTER == VFILTER_HARINAIR_KF4d
VarioFilter_HarInAirKF4d    varioFilter;
#elif USE_KALMAN_FILTER == VFILTER_ROBIN_KF
VarioFilter_RobinKF         varioFilter;
#endif


class KeypadHandler : public IKeypadCallback
{
public:
    KeypadHandler() {}

    virtual void onPressed(uint8_t key);
    virtual void onLongPressed(uint8_t key);
    virtual void onReleased(uint8_t key);
};

Variometer vario;
VarioSentence varioSentense(VARIOMETER_LK8_SENTENCE);
KeypadHandler keyHandler;
Keypad keyPad;
Beeper beeper;
uint8_t mute = 1;

CubeSentence cubeNmea;
HostCommand hostCommand;
HostCommand debugCommand;

static float altitude = 0.0f, vSpeed = 0.0f;
static float dampingFactor = 1.0f;
static uint32_t varioInterval = 1000;
static int addCount = 0;



void KeypadHandler::onPressed(uint8_t key) 
{
  LOGi("key-pressed: %d", key);

  cubeNmea.start("M3KBD");
  cubeNmea.append((int)key);
  cubeNmea.append((int)1);
  cubeNmea.finish();
}

void KeypadHandler::onLongPressed(uint8_t key) 
{
  LOGi("key-long-pressed: %d", key);

  cubeNmea.start("M3KBD");
  cubeNmea.append((int)key);
  cubeNmea.append((int)2);
  cubeNmea.finish();
}

void KeypadHandler::onReleased(uint8_t key) 
{
  LOGi("key-released: %d", key);

  cubeNmea.start("M3KBD");
  cubeNmea.append((int)key);
  cubeNmea.append((int)0);
  cubeNmea.finish();
}

void processCommand(Stream& stream, HostCommand& cmd)
{
  while (stream.available())
  {
    int code = cmd.push(stream.read());
    switch (code)
    {
    case HostCommand::CMD_MUTE:
      mute = cmd.getLastCommand().mute.state;
      LOGv("Receive Mute: %d", mute);
      if (mute)
        beeper.setMute();
      break;
    }
  }
}

void setup() 
{
  bsp_hal_init();

  #if USE_KALMAN_FILTER == VFILTER_HARINAIR_KF2
  varioFilter.begin(40.0f, 1000000.0f, 0);
  #elif USE_KALMAN_FILTER == VFILTER_HARINAIR_KF3
  varioFilter.begin(500.0f, 6000.0f, 1.0f, 0);
  #elif USE_KALMAN_FILTER == VFILTER_HARINAIR_KF4d

  // injects additional uncertainty depending on magnitude of acceleration
  // helps respond quickly to large accelerations while heavily filtering
  // in low acceleration situations.  Range : 0.5 - 1.5
  #define KF_ACCEL_VARIANCE_DEFAULT   100     // 50 ~ 150
  #define KF_ADAPT_DEFAULT            10     // 50 ~ 150

  varioFilter.begin(KF_ACCEL_VARIANCE_DEFAULT * 1000.0f, KF_ADAPT_DEFAULT / 100.0f, 0, 0, 0);
  #elif USE_KALMAN_FILTER == VFILTER_ROBIN_KF
  varioFilter.Configure(30.0f, 4.0f, altitude);
  #endif   

  vario.begin(CreateBarometer(), &varioFilter);
  keyPad.begin(CreateKeypadInput(), &keyHandler);
  beeper.begin(CreateTonePlayer());

  // outputs a sinus signal with frequency ~1000Hz and max. amplitude (default)
  //dac1.outputCW(1000);
  // outputs a sinus signal with frequency ~1000Hz, max. amplitude (default) and 180° phaseshift
  //dac2.outputCW(1000, DAC_CW_SCALE_1, DAC_CW_PHASE_180);  
}

void loop() 
{
  static uint8_t lastChar = 0;
  while (SerialGPS.available())
  {
    lastChar = SerialGPS.read();
    SerialHost.write(lastChar);
    #if DEBUG_MODE
    SerialDebug.write(lastChar);
    #endif

    if (lastChar == '\n')
      break;
  }

  if (cubeNmea.available() && (/*lastChar == 0 ||*/ lastChar == '\n'))
  {
    while (cubeNmea.available())
    {
      lastChar = cubeNmea.read();
      SerialHost.write(lastChar);
      #if DEBUG_MODE
      SerialDebug.write(lastChar);
      #endif

      if (lastChar == '\n')
        break;
    }
  }

  #if PROCESS_HOST_ONLY
  while (SerialHost.available())
  {
    int cmd = hostCommand.push(SerialHost.read());
    switch (cmd)
    {
    case HostCommand::CMD_MUTE:
      mute = hostCommand.getLastCommand().mute.state;
      LOGv("Receive Mute: %d", mute);
      if (mute)
        beeper.setMute();
      break;
    }
  }
  #else
  processCommand(SerialHost, hostCommand);
  #if DEBUG_MODE
  processCommand(SerialDebug, debugCommand);
  #endif
  #endif

  keyPad.update();
  beeper.update();

  if (vario.update() > 0)
  {
    // update vertical-speed, barometric-altitude, temperature
    float alt = vario.getAltitudeFiltered();
    float vel = vario.getVelocity();

    //altitude = altitude + (alt - altitude) * dampingFactor;
    //vSpeed = vSpeed + (vel - vSpeed) * dampingFactor;
    altitude += alt;
    vSpeed += vel;
    addCount += 1;

    // update beep, vario-nmea, ...
    if (mute == 0)
      beeper.setVelocity(vel);
  }

  static uint32_t lastTick = millis();
  if (millis() - lastTick >= varioInterval && addCount > 0)
  {
    //
    lastTick = millis();

    //
    float temp = vario.getTemperature();
    float prs = vario.getPressure();
    altitude /= addCount;
    vSpeed /= addCount;
    LOGv("Accum: %d, Altitude: %f, VSpeed: %f", addCount, altitude, vSpeed);

    cubeNmea.start("M3VAR");
    cubeNmea.append(temp, 2);
    cubeNmea.append(prs, 0);
    cubeNmea.append(altitude, 0);
    cubeNmea.append(vSpeed, 2);
    cubeNmea.append(mute ? 1 : 0);
    cubeNmea.finish();

    altitude = 0;
    vSpeed = 0;
    addCount= 0;
  }
}


// $GPXXX,...,*xx
//
// $VARIO,{pressure},{temerature},{vertical-speed}*xx
// $KEY,{key number},{key state}*xx
//

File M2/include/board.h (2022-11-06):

// board.h
//

#ifndef __BOARD_H__
#define __BOARD_H__

#include "driver/gpio.h"

/**
 * @brief ESP32-S3-HMI-DevKit LCD GPIO defination and config
 * 
 */
#define FUNC_LCD_EN     (1)
#define LCD_BIT_WIDTH   (16)

#define GPIO_LCD_BL     (GPIO_NUM_NC)
#define GPIO_LCD_CS     (GPIO_NUM_NC)
#define GPIO_LCD_RST    (GPIO_NUM_21)
#define GPIO_LCD_RS     (GPIO_NUM_38)
#define GPIO_LCD_WR     (GPIO_NUM_17)

#define GPIO_LCD_D00    (GPIO_NUM_1)
#define GPIO_LCD_D01    (GPIO_NUM_9)
#define GPIO_LCD_D02    (GPIO_NUM_2)
#define GPIO_LCD_D03    (GPIO_NUM_10)
#define GPIO_LCD_D04    (GPIO_NUM_3)
#define GPIO_LCD_D05    (GPIO_NUM_11)
#define GPIO_LCD_D06    (GPIO_NUM_4)
#define GPIO_LCD_D07    (GPIO_NUM_12)
#define GPIO_LCD_D08    (GPIO_NUM_5)
#define GPIO_LCD_D09    (GPIO_NUM_13)
#define GPIO_LCD_D10    (GPIO_NUM_6)
#define GPIO_LCD_D11    (GPIO_NUM_14)
#define GPIO_LCD_D12    (GPIO_NUM_7)
#define GPIO_LCD_D13    (GPIO_NUM_15)
#define GPIO_LCD_D14    (GPIO_NUM_8)
#define GPIO_LCD_D15    (GPIO_NUM_16)

#define LCD_DIRECTION_LANDSCAPE   (1)  // 1:landscape mode   0:portrait mode

#if LCD_DIRECTION_LANDSCAPE   // landscape mode
#define LCD_WIDTH       (800)
#define LCD_HEIGHT      (480)
#else   // portrait mode
#define LCD_WIDTH       (480)
#define LCD_HEIGHT      (800)
#endif

/**
 * @brief ESP32-S3-HMI-DevKit I2C GPIO defineation
 * 
 */
#define FUNC_I2C_EN     (1)
#define GPIO_I2C_SCL    (GPIO_NUM_39)
#define GPIO_I2C_SDA    (GPIO_NUM_40)

/**
 * @brief ESP32-S3-HMI-DevKit SPI GPIO defination
 * 
 */
#define FUNC_SPI_EN     (1)
#define GPIO_SPI_CS_SD  (GPIO_NUM_34)
#define GPIO_SPI_MISO   (GPIO_NUM_37)
#define GPIO_SPI_MOSI   (GPIO_NUM_35)
#define GPIO_SPI_SCLK   (GPIO_NUM_36)

/**
 * @brief ESP32-S3-HMI-DevKit KEY GPIO defination
 * 
 */
#define FUNC_KEY_EN     (1)
#define GPIO_KEY        (GPIO_NUM_0)

/**
 * @brief ESP32-S3-HMI-DevKit ADC GPIO defination
 * 
 */
#define FUNC_ADC_EN     (1)
#define GPIO_BAT_ADC    (GPIO_NUM_18)

/**
 * @brief ESP32-S3-HMI-DevKit I2S GPIO defination
 * 
 */
#define FUNC_I2S_EN      (1)
#define GPIO_I2S_MCLK    (GPIO_NUM_45)
#define GPIO_I2S_SCLK    (GPIO_NUM_42)
#define GPIO_I2S_LRCK    (GPIO_NUM_48)
#define GPIO_I2S_DIN     (GPIO_NUM_41)
#define GPIO_I2S_DOUT    (GPIO_NUM_47)


/**
 * @brief 
 * 
 */

#define GPIO_EXT_MASK       (0x80)

#define GPIO_EXT_IO0        (0)
#define GPIO_EXT_IO1        (1)
#define GPIO_EXT_IO2        (2)
#define GPIO_EXT_IO3        (3)
#define GPIO_EXT_LCD_BL     (4)
#define GPIO_EXT_AUDIO_PA   (5)
#define GPIO_EXT_BOOST_EN   (6)
#define GPIO_EXT_TOUCH_RST  (7)


#endif // __BOARD_H__

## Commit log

2022-09-12 page, box
    [pin-assignment.xlsx]
2022-09-15 esp32 port implement (not tested)
2022-09-19 update case-design
    [Button-Enter (Meshed).stl, Button-Guide (Meshed).stl, Button-Power (Meshed).stl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]
2022-09-20 update filter
2022-09-25 esp32 bt
2022-09-27 fixed ble-uart write error
    [main.cpp]
2022-10-05 filter(kf4d) calibration
2022-10-16 timezone API & fixed filter error
2022-10-20 H/W Test: audio, adc (TBD)
2022-10-23 M2 case
    [Case-M2.FCStd, layer.xlsx]
2022-10-30 fixed layout
    [Case-M2.FCStd]
2022-10-30 calibrate kalman-filter
2022-11-13 new ui-framework
2022-11-14 layout switching
2022-11-16 setting skeleton
    [Case-M2.FCStd]
2022-11-16 use millis() instead get_tick()
2023-03-13 m3 case
    [Disp Holder (Meshed).stl, M3.FCStd, Main Button (Meshed).stl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]
2023-04-03 fixed error of uart initialize
    [bsp.cpp]
2023-04-13 cube nmea-sentence
    [M3.FCStd]
2023-04-17 nmea parser (TBD)
    [default_16MB.csv]
2023-08-12 changed baro-filter
2023-08-16 fixed error of data loosing (TBD)
    [bsp.cpp, main.cpp]
2023-08-18 pin task to core
2023-08-21 share SPI
2023-09-24 json type error, web pages, chunked file, bt end
    [WiFiSettingWindow.cpp]
2023-10-12 xctask sample
2023-10-21 - save screen as file - change device-context
2026-07-11 M3 Case renewal
